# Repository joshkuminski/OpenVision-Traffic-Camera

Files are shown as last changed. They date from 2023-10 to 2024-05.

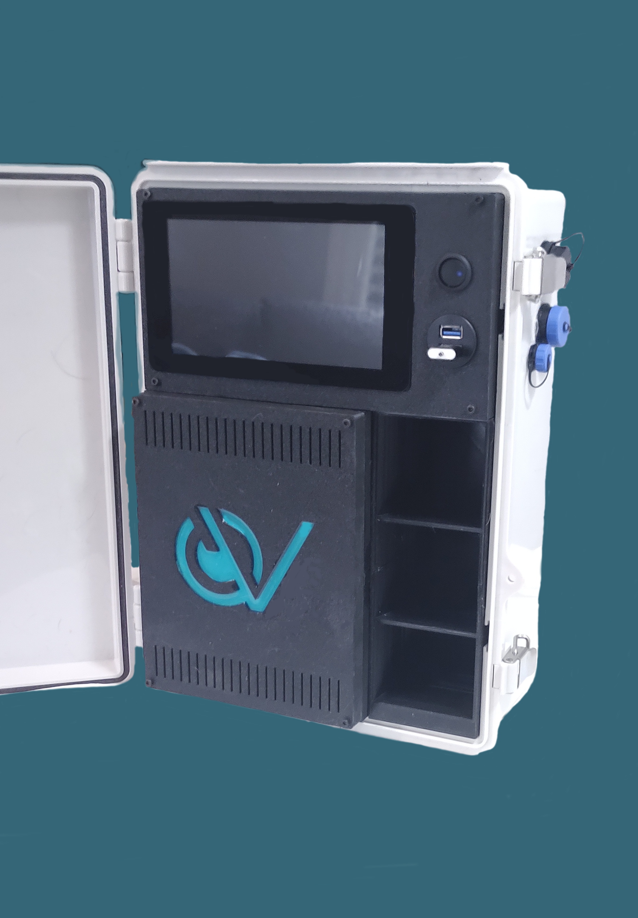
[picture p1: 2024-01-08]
Build_Images/ControlBox.jpg

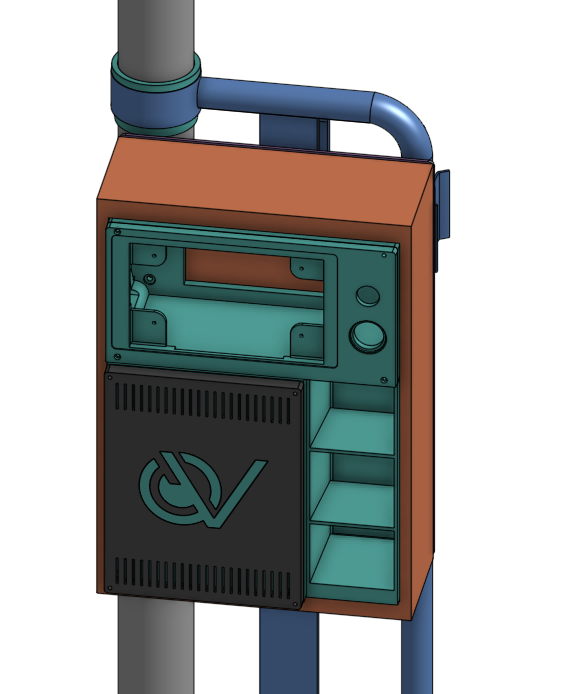
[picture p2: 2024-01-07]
Build_Images/Control_closeUp.PNG

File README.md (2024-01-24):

# OpenVision-Traffic-Camera
<p align="center">
  OpenVision
</p>

WORK IN PROGRESS

OpenVision Traffic Camera is an integral component within the [OpenVision](https://github.com/joshkuminski/OpenVision) Framework for traffic monitoring. Specifically designed for conducting intersection turning movement counts, this module harnesses the power of a Raspberry Pi 4 paired with an HQ camera to provide comprehensive traffic insights.

This is a portable, low cost (under $2,000), non-intrusive, high quality camera for recording traffic data.  With the addition of second battery pack you can hot swap packs for unlimited video recording. About 7 days of continuous recording per battery pack system. *95%+ accuracy up to 150' for a single unit (*with the OpenVision Framework).

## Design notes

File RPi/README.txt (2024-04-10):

**Running 64bit Debian Bullseye**

Place all python files in the directory: /home/pi/scripts

*** Install MySQL Database *** 
sudo apt update
sudo apt upgrade
sudo apt install mariadb-server
sudo apt install php
sudo mysql_secure_installation
sudo mysql -u root -p
CREATE DATABASE RPiCamera_db;
CREATE USER 'OpenVisionUser'@'localhost' IDENTIFIED BY 'OpenVision';
GRANT ALL PRIVILEGES ON RPiCamera_db.* TO 'OpenVisionUser'@'localhost';
FLUSH PRIVILEGES;

*** Install PHPMyAdmin *** 
sudo apt install phpmyadmin -> select apache2 web server -> select 'yes' on the next prompt. This will run you through setting up a password for PHPmyAdmin itself
sudo nano /etc/apache2/apache2.conf
  Include @ bottom: Include /etc/phpmyadmin/apache.conf
sudo service apache2 restart
sudo ln -s /usr/share/phpmyadmin /var/www/html

*** Now go to 'your pi ip'/phpmyadmin in a browser *** 
*** Create a Table Named 'CameraSchedule' with 4 Columns: *** 
ID - int - AutoIncrement
Date - Date
Time - text
Duration - int

*** Additional Packages Needed *** 
sudo apt install matchbox-keyboard
sudo apt install arduino
sudo apt-get install python3-pil python3-pil.imagetk
sudo apt install xinput-calibrator  # Then run, sudo xinput_calibrator, to calibrate the touchscreen

*** Setup RTC module *** 
sudo nano /boot/config.txt
add to the end of the file: dtoverlay=i2c-rtc,ds3231
sudo apt -y remove fake-hwclock
sudo update-rc.d -f fake-hwclock remove
sudo nano /lib/udev/hwclock-set -> comment out the following lines:
  #if [ -e /run/systemd/system ] ; then
  #    exit 0
  #fi

*** Turn Off Backlight ***
sudo chmod 777 /sys/class/backlight/10-0045/bl_power
echo 1 > /sys/class/backlight/10-0045/bl_power

# Enable Right-click emulation
# edit file /etc/X11/xorg.conf
Section "InputClass"
   Identifier "calibration"
   Driver "evdev"
   MatchProduct "FT5406 memory based driver"

   Option "EmulateThirdButton" "1"
   Option "EmulateThirdButtonTimeout" "750"
   Option "EmulateThirdButtonMoveThreshold" "30"
EndSection

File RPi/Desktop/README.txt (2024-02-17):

.desktop files go on the pi Desktop
to add the file to the Applications Menu run:
sudo mv CameraUI.desktop /usr/share/applications/

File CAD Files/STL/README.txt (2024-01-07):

Suffix Key:
N - Nylon - Used for strength and low coeifficient of friction (enclosure and high temperature printer)
GFN - Glass Fiber Nylon - Used for strength (enclosure and high temperature printer)
PLA - General use (inside control box) (any printer)
ASA - Used for dimensional accuracy and UV resistance (enclosure needed + moderate temp)

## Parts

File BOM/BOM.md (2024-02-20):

1. Raspberry Pi 4 (4GB or higher) [Amazon](https://www.amazon.com/Raspberry-Pi-4-4G-Model/dp/B081YD3VL5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)
2. Aluminum heak sink for pi [Amazon](https://www.amazon.com/dp/B091L1XKL6?psc=1&ref=ppx_yo2ov_dt_b_product_details)
3. Arduino Uno [Amazon](https://www.amazon.com/Arduino-A000066-ARDUINO-UNO-R3/dp/B008GRTSV6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)
4. HQ Camera [Amazon](https://www.amazon.com/Arducam-Raspberry-Camera-Sensitivity-Adapter/dp/B09YHN5DBY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)
5. CSI to USB camera adapter [Amazon](https://www.amazon.com/dp/B08NVG2CY4?psc=1&ref=ppx_yo2ov_dt_b_product_details)
6. Wide Anlge Lens for HQ [Amazon](https://www.amazon.com/Arducam-Degree-Raspberry-Camera-Length/dp/B08GLYR572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) OR [Ali Express](https://www.aliexpress.us/item/3256806167870673.html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)
7. Waterproof Box [Amazon](https://www.amazon.com/QILIPSU-Waterproof-Electrical-Enclosure-Weatherproof/dp/B0BWK5LXTR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)
8.
9. SD card 32GB & 128GB [32GB](https://www.amazon.com/SanDisk-Extreme-Mobile-Gaming-microSD/dp/B089M5KV4Y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) [128GB](https://www.amazon.com/SanDisk-Extreme-Mobile-Gaming-microSD/dp/B089DNG977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)
10. 12V 15Ah SLA battery [Amazon](https://www.amazon.com/dp/B00K8V2FUE?ref=ppx_yo2ov_dt_b_product_details&th=1)
11. Single Relay Board [Amazon](https://www.amazon.com/HiLetgo-Channel-optocoupler-Support-Trigger/dp/B00LW15A4W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)
12. Servo (2) [Amazon](https://www.amazon.com/Miuzei-Torque-Digital-Waterproof-Control/dp/B07HNTKSZT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)
13. Servo brackets [Amazon](https://www.amazon.com/Servo-Mount-Bracket-MG996R-Steering/dp/B07PQ12TXS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)
14. Cableing: 30ft USB 3.0 cable [Amazon](https://www.amazon.com/GearIT-Extension-Female-Repeater-Playstation/dp/B09TMX967R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), 30ft of 4-wire cable 24AWG or larger [Amazon](https://www.amazon.com/24AWG-UL2464-Power-Yellow-Conductors/dp/B07TJGPB4S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), 1ft USB A to micro B [Amazon](https://www.amazon.com/dp/B09XK4JDBJ?psc=1&ref=ppx_yo2ov_dt_b_product_details), USB-C to to 2-pin bare [Amazon](https://www.amazon.com/dp/B0CCYVFQSX?ref=ppx_yo2ov_dt_b_product_details&th=1), 4-port USB 3.0 Hub [Amazon](https://www.amazon.com/dp/B0BFGSCTNN?psc=1&ref=ppx_yo2ov_dt_b_product_details), Dupont Cables [Amazon](https://www.amazon.com/Elegoo-EL-CP-004-Multicolored-Breadboard-arduino/dp/B01EV70C78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),
15. Joystick [Adafruit](https://www.adafruit.com/product/512)
16. Toggle Switch [Amazon](https://www.amazon.com/Nilight-90013L-Toggle-Control-Warranty/dp/B07T1JG6BD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)
17. Raspberry Pi 7" Touchscreen [Amazon](https://www.amazon.com/dp/B0153R2A9I?psc=1&ref=ppx_yo2ov_dt_b_product_details)
18. Buck converter [Amazon](https://www.amazon.com/UCTRONICS-Converter-Transformer-Voltage-Regulator/dp/B07XXWQ49N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)
19. RTC module [Amazon](https://www.amazon.com/dp/B07W6Y4P99?psc=1&ref=ppx_yo2ov_dt_b_product_details)
20. CR1220 battery [Amazon](https://www.amazon.com/dp/B003CU3E2Q?psc=1&ref=ppx_yo2ov_dt_b_product_details)
21. Cable Connections: (2) 4-pin bulkhead [Amazon](https://www.amazon.com/dp/B07DGVC786?ref=ppx_yo2ov_dt_b_product_details&th=1), (2) 2-pin large bulkhead [Amazon](https://www.amazon.com/SZJELEN-2Pin-12Pin-Waterproof-Circular-Connector/dp/B07DCKRTRQ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), USB bulkhead [Amazon](https://www.amazon.com/CNLINKO-Connector-Receptacles-Waterproof-Industrial/dp/B079957VC3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), 2-port USB bulkhead [Amazon](https://www.amazon.com/ICESPRING-Female-Extension-Motorcycle-Dashboard/dp/B01MY1WDIU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)
22. Anti corrosion lube [Amazon](https://www.amazon.com/dp/B000K8ZZ3O?psc=1&ref=ppx_yo2ov_dt_b_product_details)
23. Neodymium magnets [Amazon](https://www.amazon.com/dp/B072K5SLXK?psc=1&ref=ppx_yo2ov_dt_b_product_details)
24. Lock Collars [Amazon](https://www.amazon.com/Befenybay-Collar-Shaft-Screw-Printer/dp/B07V41FRZS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)
25. Stainless steel shaft [Amazon](https://www.amazon.com/Eowpower-Linear-Motion-Shaft-Hardened/dp/B01NCOMFLT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)
26. Bearings [Amazon](https://www.amazon.com/QINGZHENG-6001-2RS-Bearings-12x28x8mm-Bearing/dp/B0BJDCXHKB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)
27. Handle [Amazon](https://www.amazon.com/TEANTECH-Handles-Replacement-Accessory-Suitcase/dp/B07VP13LXT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)
28. Padlocks [Amazon](https://www.amazon.com/Solid-Brass-Keyed-Alike-Hardened-Steel-Brass-Keys-Locker-Lock/dp/B07B8XPV5T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)
29. Ratchet Straps [Amazon](https://www.amazon.com/STANLEY-S1007-Yellow-Ratchet-Straps/dp/B07V6X65QD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)
30. Carrying Case [Lowes](https://www.lowes.com/collections/Kobalt-CASESTACK-Storage-Accessories-Collection/GR_8633)
31. JB Weld 5min epoxy [Amazon](https://www.amazon.com/J-B-Weld-ClearWeld-Syringe-25mL/dp/B09C6R4VSQ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)
32. 38' fiberglass mast [MGS](https://mgs4u.com/product/38-feet-heavy-duty-fiberglass-push-up-mast-mk-6-hd/)
33. 1/4" Aluminum Plate
34. 1/4" Aluminum Flat Bar (3/16" x 2" x 4') 
35. 1" ALuminum tube
36. 3" Aluminum tube
37. 3D Printed Parts (see CAD Folder)
    - GF Nylon [Amazon](https://www.amazon.com/YXPOLYER-Reinforced-Filament-Engineering-Increased/dp/B09ZXL1J6V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)
    - PLA [Amazon](https://www.amazon.com/ELEGOO-Filament-Stronger-Dimensional-Accuracy/dp/B0C14PVBPB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)
    - ASA [Amazon](https://www.amazon.com/dp/B0CD18NM4K?psc=1&ref=ppx_yo2ov_dt_b_product_details)

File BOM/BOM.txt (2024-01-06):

1. Raspberry Pi 4 (4GB or higher)
2. Raspberry Pi Pico
3. HQ Camera
4. Wide Anlge Lens for HQ
5. 
3. Single Relay Board
4. Cableing: 30ft USB 3.0 cable, 30ft of 4-wire cable 20AWG or larger, 1ft USB micro to USB, USB-C to USB, 4-port USB 3.0 Hub, 
5. Joystick
6. Raspberry Pi 7" Touchscreen
7. Buck converter
8. RTC module w/ CR1220 battery
9. Cable Connections: 4-pin bulkhead, 2-pin large bulkhead, USB bulkhead, 2-port USB bulkhead, 
X. Lots of 3D Printed Parts (see CAD Folder)

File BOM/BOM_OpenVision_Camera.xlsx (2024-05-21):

Control Box / Camera / Mounting |  |  |  |  | Additional Power Supply
 |  | QTY |  |  |  |  | QTY
Raspberry Pi 4B | Amazon | 1 | $85.39 | $85.39 | 12V 15Ah SLA Batteries | Amazon | 5 | $36.99 | $184.95 | (50+ hours recording)
Aluminum heat sink for Pi | Amazon | 1 | $10.99 | $10.99 | Waterproof Box | Amazon | 1 | $54.99 | $54.99
Arduino | Amazon | 1 | $27.60 | $27.60 | Handle | Amazon | 1 | $9.99 | $9.99
Pi HQ Camera | Amazon | 1 | $59.99 | $59.99 | 2-pin large bulkhead | Amazon | 1 | $10.80 | $10.80
Raspberry Pi 7" Touchscreen | Amazon | 1 | $91.08 | $91.08 | Spray Foam | Amazon | 1 | $17.60 | $17.60
CSI to USB | Amazon | 1 | $39.99 | $39.99 |  |  |  |  | $278.33
Wide angle lens | Amazon | 1 | $34.99 | $34.99
Waterproof Box | Amazon | 1 | $54.99 | $54.99
micro SD card -128GB | Amazon | 1 | $19.99 | $19.99
Compact SD to USB | Amazon | 1 | $10.49 | $10.49
12V 15Ah SLA Batteries | Amazon | 2 | $36.99 | $73.98
12V 9Ah SLA Batteries | Amazon | 0 | $29.99 | $0.00
12V battery Charger (1500mA) | Amazon | 2 | $10.98 | $21.96
Relay Board | Amazon | 1 | $7.39 | $7.39
Servo | Amazon | 2 | $12.99 | $25.98
Servo Brackets | Amazon | 1 | $12.99 | $12.99
30ft USB Cable | Amazon | 1 | $39.99 | $39.99
3ft USB Cable | Amazon | 1
24AWG 4-wire Cable | Amazon | 1 | $30.99 | $30.99
1ft USB A to Micro | Amazon | 1 | $7.99 | $7.99
USB C to 2-pin bare | Amazon | 1 | $8.99 | $8.99
4-port USB 3.0 Hub | Amazon | 1 | $7.19 | $7.19
Dupont Cables | Amazon | 1 | $6.98 | $6.98
Toggle Switch | Amazon | 1 | $6.99 | $6.99
Joystick | Adafruit | 1 | $5.95 | $5.95
Buck Converter | Amazon | 1 | $14.99 | $14.99
RTC Module | Amazon | 1 | $20.73 | $20.73
CR1220 battery | Amazon | 1 | $6.99 | $6.99
4-pin bulkhead | Amazon | 2 | $7.89 | $15.78
2-pin large bulkhead | Amazon | 2 | $10.80 | $21.60
USB 3.0 Bulkhead | Amazon | 1 | $15.29 | $15.29
2 port USB 3.0 Bulkhead | Amazon | 1 | $9.80 | $9.80
Anti-Corrosion Lube | Amazon | 1 | $9.66 | $9.66
Neodymium Magnets | Amazon | 1 | $15.99 | $15.99
Lock Collars (2) | Amazon | 1 | $8.99 | $8.99
Stainless Steel Shaft | Amazon | 1 | $9.99 | $9.99
Bearings (2) | Amazon | 1 | $10.69 | $10.69
Handle | Amazon | 1 | $9.99 | $9.99
JB Weld | Amazon | 1 | $12.20 | $12.20
Padlocks (4 pack) | Amazon | 1 | $19.99 | $19.99
Ratchet Straps (2 pack) | Amazon | 1 | $21.79 | $21.79
Carrying Case | Lowes | 1 | $218.96 | $218.96
GF Nylon | Amazon | 1 | $43.99 | $43.99
PLA filament | Amazon | 2 | $13.99 | $27.98
ASA filament | Amazon | 2 | $15.99 | $31.98
38ft Fiberglass Mast System | MGS | 1 | $329.95 | $329.95
18ft Fiberglass Mast System | MGS | 1 | $229.95 | $229.95
Aluminum Sheet (1ft x 4ft) | Metals Depot | 1 | $92.00 | $92.00
Aluminum Flat Bar (3/16" x 2" x 4') | Metals Depot | 1 | $16.32 | $16.32
Aluminum Plate (1/4" x 1'x1') | Metals Depot | 2 | $39.74 | $79.48
Aluminum Tube (3"OD x .125 wall x 2') | Metals Depot | 1 | $50.88 | $50.88
Aluminum Tube (1"OD x .065 wall x 4') | Metals Depot | 1 | $18.56 | $18.56
 |  |  | Subtotal | $2057.39

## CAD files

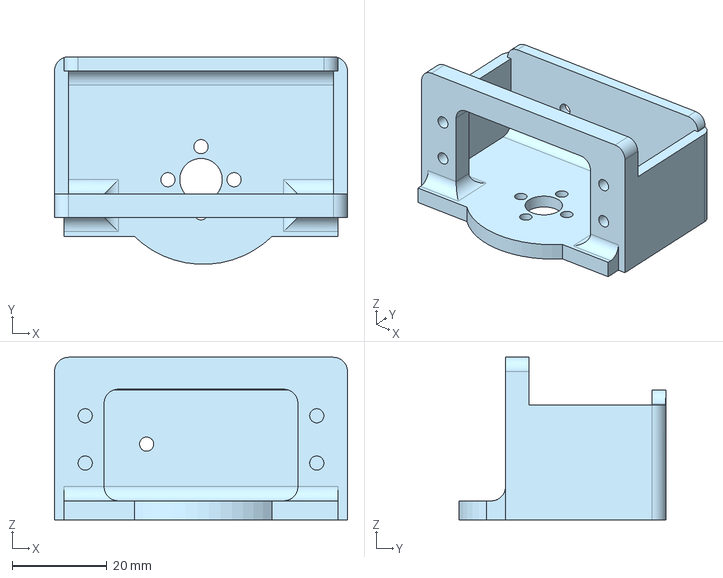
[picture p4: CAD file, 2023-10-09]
CAD Files/Servo_Mount.step
62.0 x 43.9 x 34.4 mm

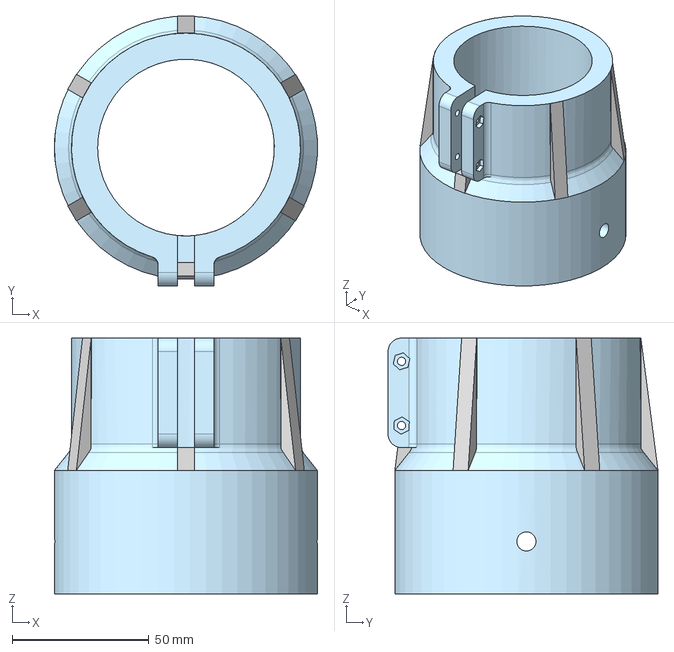
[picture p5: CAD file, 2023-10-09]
CAD Files/Coupler.step
96.0 x 98.5 x 93.4 mm

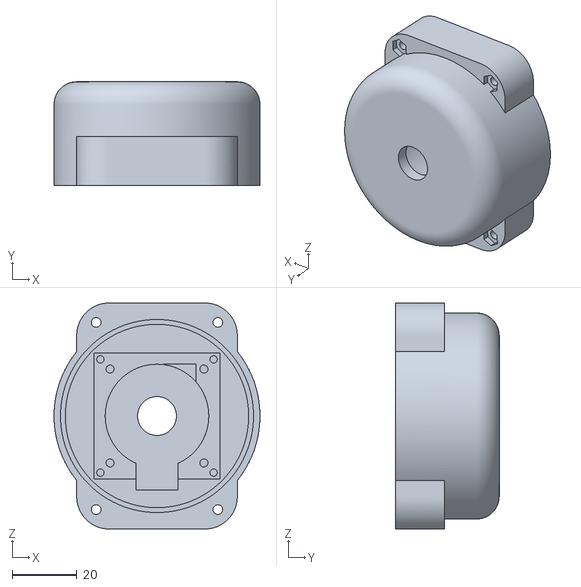
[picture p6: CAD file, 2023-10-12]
CAD Files/STL/Camera_Housing_Back_ASA.stl
63.6 x 32.0 x 69.8

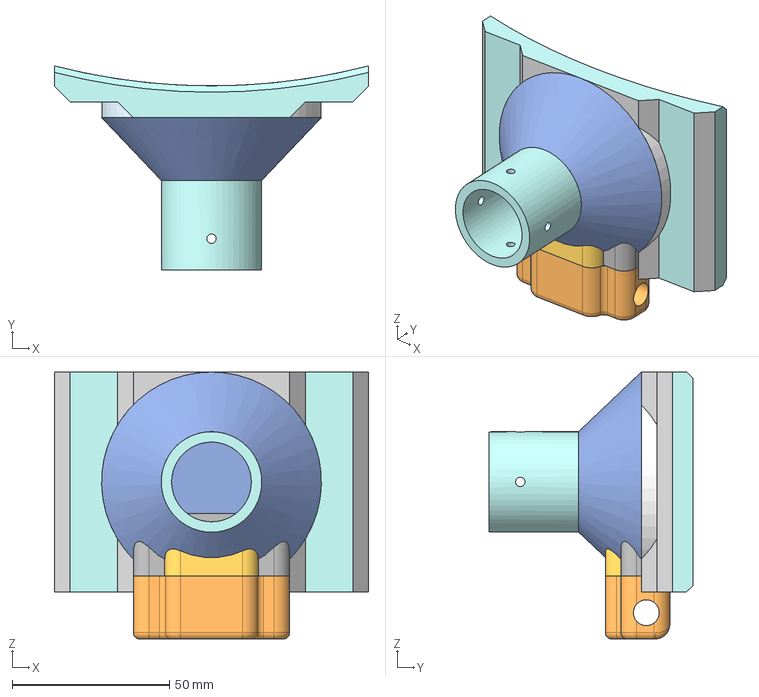
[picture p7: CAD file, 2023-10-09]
CAD Files/Magnetic_Stabilizer.step
100.0 x 65.0 x 85.0 mm

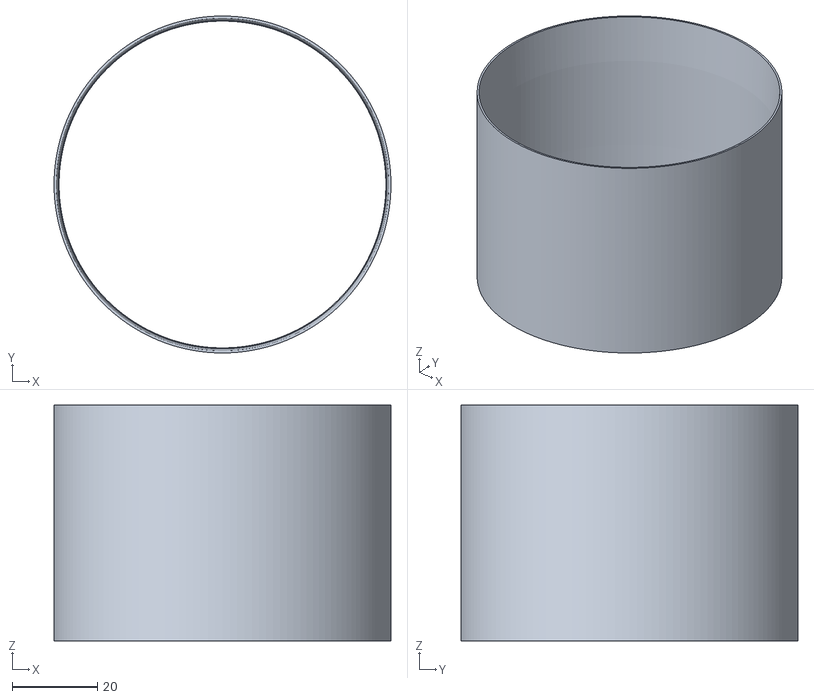
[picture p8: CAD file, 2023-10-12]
CAD Files/STL/Base_Bushing_N.stl
79.0 x 79.0 x 55.3

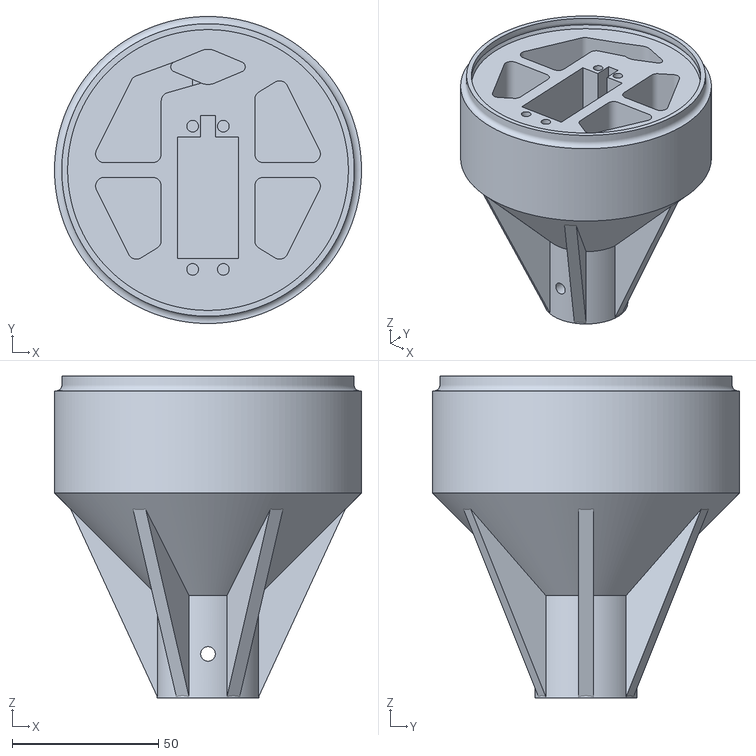
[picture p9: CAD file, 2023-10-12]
CAD Files/STL/Servo_Housing_Bottom_ASA.stl
105.0 x 105.0 x 110.0

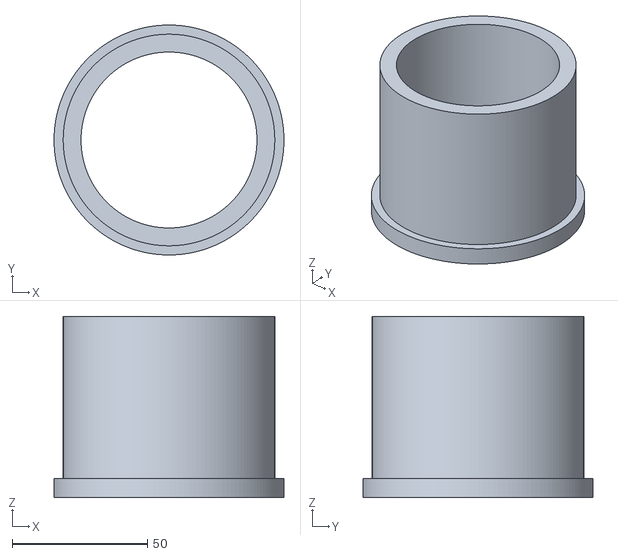
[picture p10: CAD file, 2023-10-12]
CAD Files/STL/Nylon_Bushing.stl
85.0 x 85.0 x 67.0

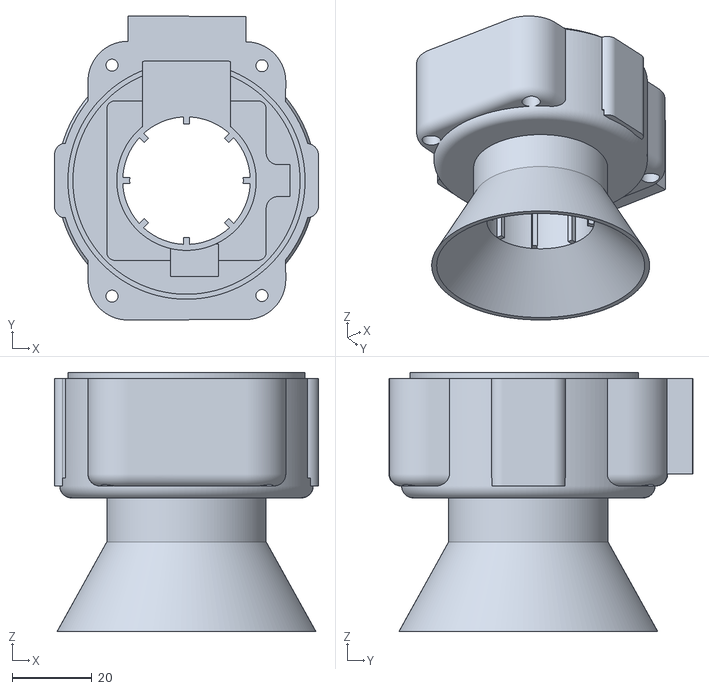
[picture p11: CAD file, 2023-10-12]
CAD Files/STL/Camera_Housing_Front_ASA.stl
66.3 x 76.3 x 65.0

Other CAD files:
CAD Files/STL/Servo_Housing_Top_ASA.stl
CAD Files/STL/Coupler_GFN.stl

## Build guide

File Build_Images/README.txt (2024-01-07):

Aqua = 3D Printed Parts
Blue = Aluminum Parts
Gray = Fiberglass Parts
Red = ControlBox

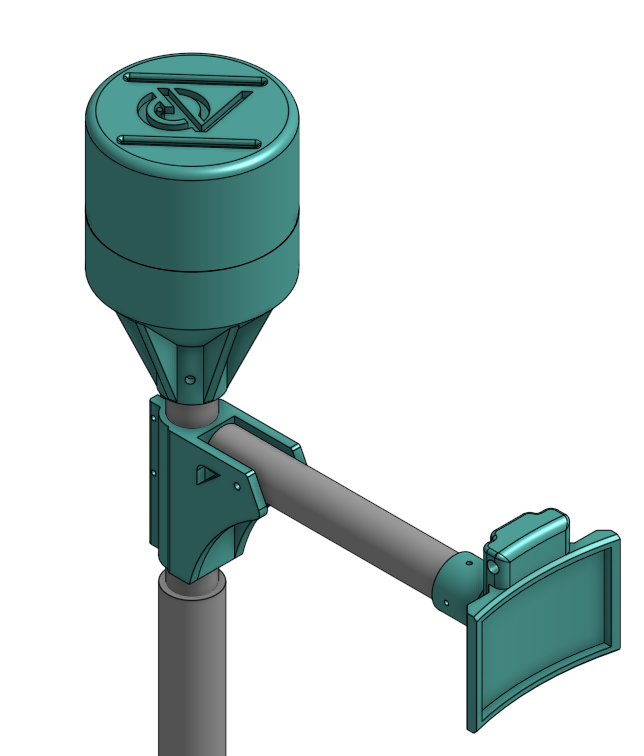
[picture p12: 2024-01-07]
Build_Images/Top_closeUp.PNG

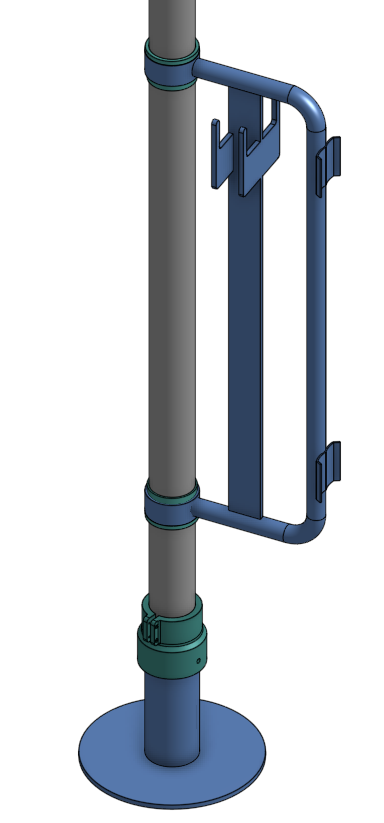
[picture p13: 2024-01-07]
Build_Images/Bottom Closeup.PNG

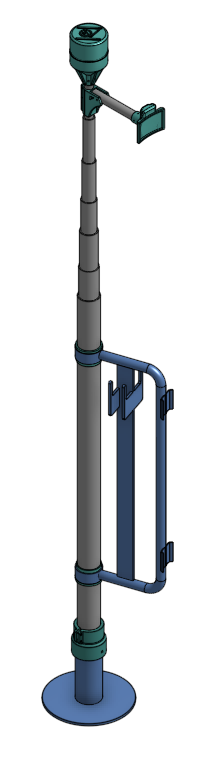
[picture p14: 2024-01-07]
Build_Images/3D Model_iso_color.PNG

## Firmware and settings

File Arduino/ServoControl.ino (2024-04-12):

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
#define joyX A1 //Tilt
#define joyY A0 //Pan
#define ReadVolt A2
#define SERVO_POSITION_ADDRESS_X 0
#define SERVO_POSITION_ADDRESS_Y 1

#include <Servo.h> //Needs to be added via library manager
#include <EEPROM.h>

Servo servo1;
Servo servo2;

unsigned long currentMillis, EEPROMMillis, RelayMillis;
unsigned long writeToEEPROM = 120000; //Set EEPROM every 30 min.
unsigned long RelayTimer = 1200000; //Initialization of Relay Timer
int storedPosition_X, storedPosition_Y;
long xValue, yValue;
const int numReadings = 10; // Number of consecutive readings to compare
long X_readings[numReadings]; // Array to store the readings
long Y_readings[numReadings]; // Array to store the readings
int xIndex = 0; 
int yIndex = 0; 
int xMaxAngle = 145; //Maximum servo1 angle
int xMinAngle = 95; //Minimun servo angle
int yMinAngle = 0; 
int yMaxAngle = 270; //Maximum servo2 angle
float NewPos = 0;
unsigned int pos1 = 110;
unsigned int pos2 = 90;
bool allZero = false;// Flag to indicate if all readings are the same
bool newData = false; 
const byte numChars = 10;
char receivedChars[numChars];
const int RELAY_PIN = 4;
bool state = false;


void setup() {
  Serial.begin(115200);
  
  servo1.attach(11);
  servo2.attach(9);

  pinMode(RELAY_PIN, OUTPUT);
  
  // Read the stored position from EEPROM
  storedPosition_X = EEPROM.read(SERVO_POSITION_ADDRESS_X);
  storedPosition_Y = EEPROM.read(SERVO_POSITION_ADDRESS_Y);
  
  // Check if a position is stored in EEPROM
  if (storedPosition_X == 255) { // EEPROM default value is 255
    //Initialize servo positions
    servo1.write(pos1);
    servo2.write(pos2);
      
  } else {
    // Set the Servos to last stored Pos
    servo1.write(storedPosition_X);
    servo2.write(storedPosition_Y);
  }
   for (int i = 0; i < numReadings; i++) {
    X_readings[i] = 1; // Initialize the readings array
    Y_readings[i] = 1; 
  }
  
  //Serial.println("Servos Initiated, please wait...");
  //wait 1min to plug in joystick and pi to power up. If joystick is not plugged in the servos may go crazy
  //delay(60000);

}

 
void loop() {
  currentMillis = millis();
  
  if (currentMillis - EEPROMMillis >= writeToEEPROM)
  {
    saveToEEPROM(pos1, pos2);
  }
  
  if (currentMillis - RelayMillis >= RelayTimer)
  {
    digitalWrite(RELAY_PIN, LOW);
  }
  
  if (currentMillis - VoltageMillis >= VoltageTimer)
  {
    //Check Voltage
    
  }
  
    //Activate Servo if LDR value is greater than 250.
    xValue = analogRead(joyX);    
    yValue = analogRead(joyY);
    
    //Need 10 readings to all equal XX before proceeding
    X_readings[xIndex] = xValue;
    Y_readings[yIndex] = yValue;
    
    if (allZero = true){
      //no nothing
    }
    else{
      for (int i = 1; i < numReadings; i++) {
        if ((X_readings[i] < 460 && X_readings[i] > 380)||(Y_readings[i] < 460 && Y_readings[i] > 380)) {
          allZero = false;
          break;
        }
        else{
          allZero = true;
          
        }
      }
    }
    
    if (allZero){
      //Servo 1 movements
      if ((xValue > 500) && (yValue > 250)){
        if (pos1 < xMaxAngle){
          servo1.write(pos1);
          pos1++;
          delay(30);
        }
      }
      if ((xValue < 150) && (yValue > 250)){
        if (pos1 > xMinAngle){
          servo1.write(pos1);
          pos1--;
          delay(30);
        }
      }
    
      //Servo 2 movements
      if ((yValue > 500) && (xValue > 250)){
        if (pos2 < yMaxAngle){
          servo2.write(pos2);
          pos2++;
          delay(30);
        }
      }
      if ((yValue < 150) && (xValue > 250)){
        if (pos2 > yMinAngle){
          servo2.write(pos2);
          pos2--;
          delay(30);
        }
      }
     }  

  recvWithStartEndMarkers();                                            // Gather data sent from Pi over serial
  processSerialData();
  newData = false;
}



void recvWithStartEndMarkers()                                        // Function to receive serial data from Pi in format of "<MESSAGE>"
{
  static boolean recvInProgress = false;
  static byte ndx = 0;
  char startMarker = '<';
  char endMarker = '>';
  char rc;

  while (Serial.available() > 0 && newData == false){
    rc = Serial.read();
    //Serial.println(rc);
    if (recvInProgress == true)
    {
      if (rc != endMarker)
      {
        receivedChars[ndx] = rc;
        ndx++;
        if (ndx >= numChars)
        {
          ndx = numChars - 1;
        }
      }
      else
      {
        receivedChars[ndx] = '\0'; //Terminate the string
        recvInProgress = false;
        ndx = 0;
        newData = true;
      }
    }

    else if (rc == startMarker)
    {
      recvInProgress = true;
    }
  }
}



void processSerialData()
{
  if (newData == true)
  {
    char commandChar = receivedChars[0];
    switch (commandChar)
    {
      case 'R':                                                      // Relay feedback. Message format is "<DELAY IN SECONDS>"
        {
          int boardNumber;
          int relayNumber;
          int relayPower;
          char* strtokIndx;  
          char buff[18];
          
          strtokIndx = strtok(receivedChars, ":");                   // Skip the first segment which is the 'R'
          strtokIndx = strtok(NULL, ":");                            // Get the board number
          boardNumber = atol(strtokIndx);
          long Relay_delay = boardNumber * 60; // Time in s
          Serial.println(Relay_delay);
          Serial.println("End Transmission");
          delay(100);
          // Set the RelayTimer millis so that the relay turns back on after X seconds
          RelayMillis = currentMillis;
          RelayTimer = Relay_delay * 1000; //Time in ms
          saveToEEPROM(pos1, pos2); //Save the position of the camera before shutting down
          delay(100);
          digitalWrite(RELAY_PIN, HIGH);
          break;
        }
    }
    newData = false;
  }
}


void saveToEEPROM(int Pos1, int Pos2){
  // Write the default position (zero) to EEPROM
    EEPROM.write(SERVO_POSITION_ADDRESS_X, Pos1);
    EEPROM.write(SERVO_POSITION_ADDRESS_Y, Pos2);
    EEPROMMillis = millis();
    writeToEEPROM = writeToEEPROM * 2;  //Increase the time we write to EEPROM
}

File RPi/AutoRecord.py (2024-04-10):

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
import mysql.connector
import datetime
import subprocess
import threading
import time
import queue
import cv2
import os
import serial


def AddEntry():
    Date='2023-05-05'
    Time='0839'
    Duration = 5

    # Select All from Table
    mycursor.execute("SELECT * FROM CameraSchedule")
    for x in mycursor:
        pass
        #print(x)
        
    #Insert into Table
    mycursor.execute("INSERT INTO CameraSchedule (Date, Time, Duration) VALUES (%s,%s,%s)",(Date, Time, Duration))
    
    db.commit()
    

def getNextEntry():
    # Select all rows and order by date and time
    mycursor.execute("SELECT * FROM CameraSchedule ORDER BY Date, Time")
    rows = mycursor.fetchall()
    
    current_record = rows[0]

    # Get the earliest date and time from the first row
    earliest_time_str = str(rows[0][2])
    earliest_hours = int(earliest_time_str[:2])
    earliest_minutes = int(earliest_time_str[2:])
    earliest_date = datetime.datetime.strptime(str(rows[0][1]), '%Y-%m-%d')
    earliest_date_time = earliest_date.replace(hour=earliest_hours, minute=earliest_minutes)

    # Get the current date and time
    current_date_time = datetime.datetime.now()
    
    # Calculate the time difference
    time_difference = earliest_date_time - current_date_time
    
    if int(time_difference.total_seconds()) > 0:
        if int(time_difference.total_seconds()) > 900: # if greater than 15min -> shutdown pi     
            off_duration = int(time_difference.total_seconds() - 300)  # give it 5 min to boot up before recording
            #print(off_duration)
            if R_count == 0:
                time.sleep(900)
                off_duration = off_duration - 900
                shutDownPi(off_duration)
            else:
                shutDownPi(off_duration)
        else:
            timer = threading.Timer(int(time_difference.total_seconds()), lambda: None)
            timer.start()
            start_time = time.time()
            #print("timer started for " + str(time_difference) + " min.")
            
            # This will stay in a loop until timer expires
            while timer.is_alive():
                elapsed_time = time.time() - start_time
                # check DB every 15min = 900 sec
                if elapsed_time > 900:
                    
                    # reload the database
                    mycursor.execute("FLUSH TABLES;")
                    mycursor.execute("FLUSH PRIVILEGES;")
                    mycursor.execute("SET GLOBAL general_log = 'OFF';")
                    mycursor.execute("SET GLOBAL general_log = 'ON';")
                    
                    mycursor.execute("SELECT * FROM CameraSchedule ORDER BY Date, Time")
                    rows = mycursor.fetchall()
                    
                    if rows[0] != current_record:
                        #print("new receord found")
                        return
                    
                    start_time = time.time()
                    #print("No new record found")
                    
                continue

            # convert min to frames = time * 60 s/min * 15fps
            #duration = int(rows[0][3]) * 60 * 15
            duration = int(rows[0][3]) * 60
            
            date_time = datetime.datetime.now()
            date_time = date_time.strftime("%Y-%m-%d_%H-%M-%S")
            
            usb_ls = check_usb_devices()
            
            mount_location = '/media/OpenVision/RPi'
            if usb_ls and os.path.exists(mount_location):
                out = '/media/OpenVision/RPi/Output_{}.mp4'.format(date_time)
            else:
                out = '/home/OpenVision/Videos/Output_{}.mp4'.format(date_time)

            # Call the Camera Record method
            #opencv_record_video(duration)
            ffmpeg_record_video(out, duration)
            
            # Delte entry after sending to the Camera Record Script
            mycursor.execute('DELETE FROM CameraSchedule WHERE CameraSchedule.ID=%s', (rows[0][0],))
            
    else:
        mycursor.execute('DELETE FROM CameraSchedule WHERE CameraSchedule.ID=%s', (rows[0][0],))
        
    db.commit()
    

def check_usb_devices():
    try:
        # Run the lsusb command and capture its output
        result = subprocess.run(['lsusb'], capture_output=True, text=True)
        
        # Check if the command was successful (return code 0)
        if result.returncode == 0:
            if "microSD" in result.stdout:
                return True
        else:
            print(f"Error: {result.stderr}")
    except Exception as e:
        print(f"An error occurred: {e}")


def put_screen_to_sleep():
    #subprocess.run(["vcgencmd", "display_power", "0"])
    subprocess.run("echo 1 >/sys/class/backlight/10-0045/bl_power", shell=True)
    

def ffmpeg_record_video(output_file, duration=60):
    # Define FFmpeg command to record video
    ffmpeg_command = [
        'ffmpeg',
        '-loglevel', 'quiet',     # set the logging to quiet (off)
        '-f', 'v4l2',            # Input format (video4linux2 for Raspberry Pi camera)
        '-framerate', '15',      # Frame rate
        '-video_size', '2560x1440',  # Video resolution
        '-i', '/dev/video0',    # Input device (change as needed)
        '-t', str(duration),    # Duration of recording in seconds
        '-vf', 'scale=1280:720',# Scale to 720p for Post Processing
        '-c:v', 'libx264',      # Video codec
        '-preset', 'ultrafast', # Preset for speed
        '-pix_fmt', 'yuv420p',  # Pixel format
        output_file             # Output file path
    ]
    try:
        put_screen_to_sleep()
        # Run FFmpeg command
        #subprocess.run(ffmpeg_command)
        ffmpeg_process = subprocess.Popen(ffmpeg_command)
        ffmpeg_process.wait()
    except subprocess.CalledProcessError as e:
        print(e)
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

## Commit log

2023-10-09 Update and rename CameraGUI_5_customtk.py to GUI.py
2024-01-07 Update and rename Servo_Housing_Top_PET.stl to Servo_Housing_Top_ASA.stl
    [Servo_Housing_Top_ASA.stl]
2024-01-13 Update and rename BOM.txt to BOM.md

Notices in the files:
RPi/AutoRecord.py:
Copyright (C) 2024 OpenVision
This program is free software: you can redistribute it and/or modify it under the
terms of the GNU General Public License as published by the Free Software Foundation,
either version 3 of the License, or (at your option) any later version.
